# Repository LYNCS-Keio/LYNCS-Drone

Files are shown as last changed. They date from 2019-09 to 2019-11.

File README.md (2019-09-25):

# LYNCS-Drone

## Todo
- [ ] ESP32とRaspberry Pi 3間でUARTを使えるようにする
- [x] ESP32でSPI(ESP32がmaster)を使えるようにする
- [ ] MPU9255から姿勢を取得する
- [x] DPS310から温度・気圧を取得する
- [x] DPS310から高度を取得する
- [ ] ESCを使えるようにする
- [ ] 制御する

# Appearance
## 基板完成予想図
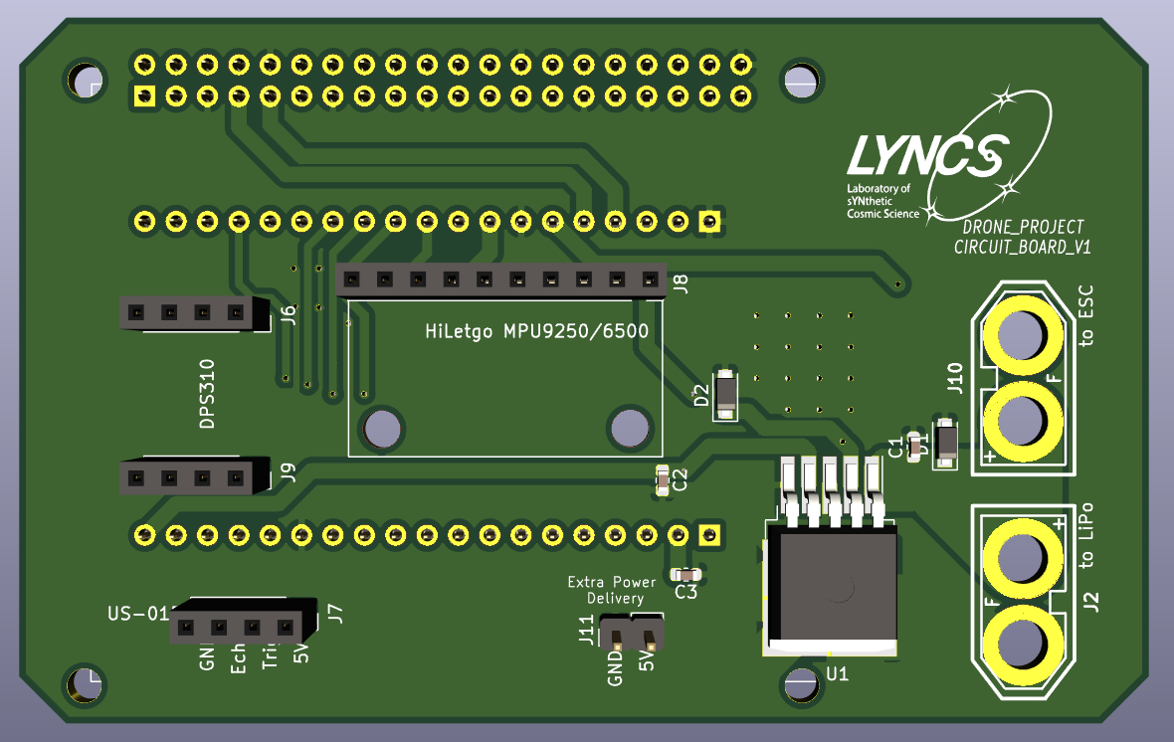
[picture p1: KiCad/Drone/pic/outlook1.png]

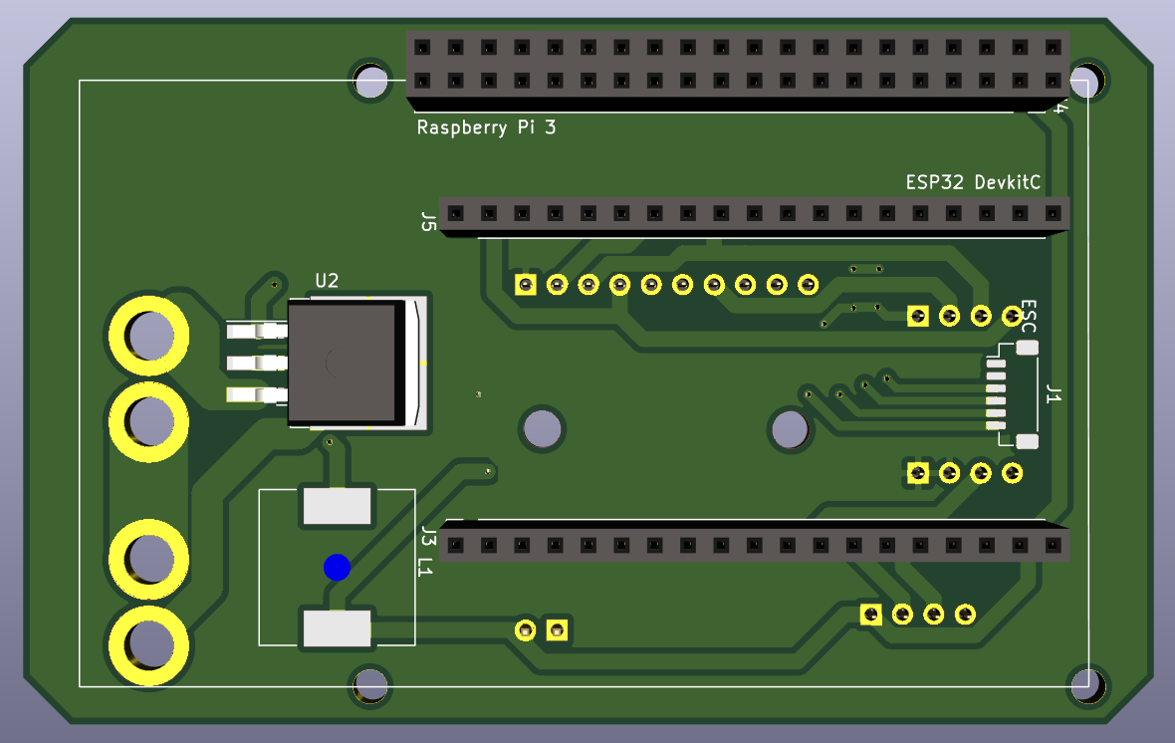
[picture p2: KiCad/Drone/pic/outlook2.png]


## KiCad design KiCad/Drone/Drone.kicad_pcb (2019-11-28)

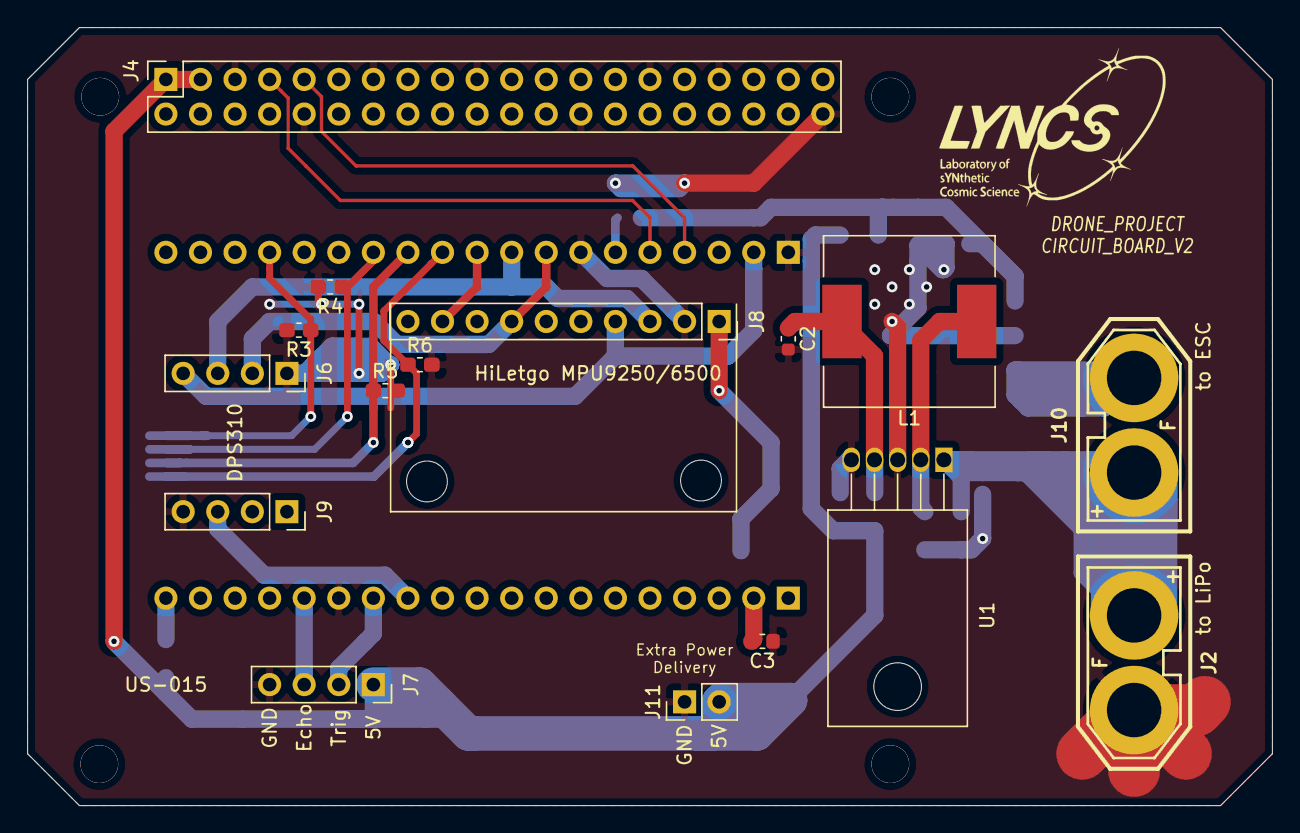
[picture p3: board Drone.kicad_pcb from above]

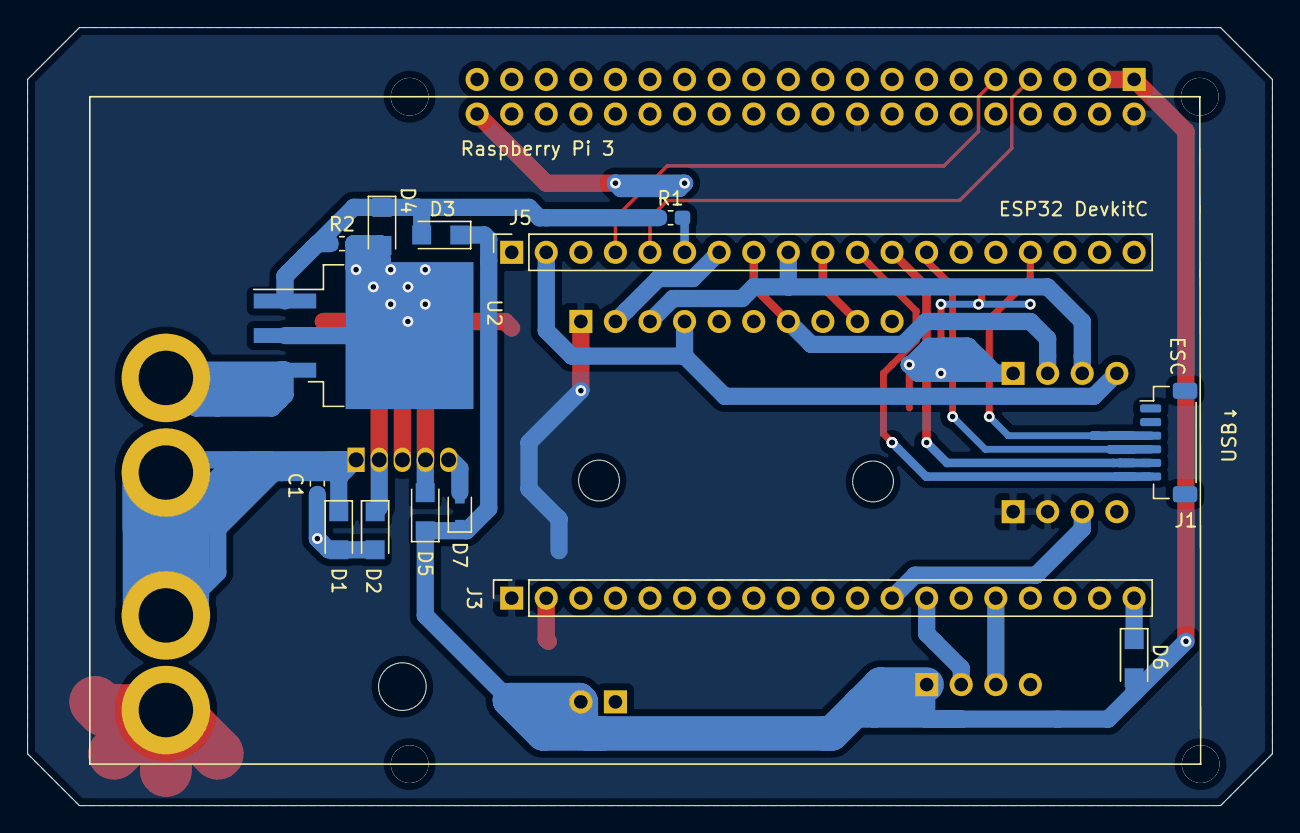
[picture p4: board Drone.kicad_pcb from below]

Board: 2 copper layers, 91.4 x 57.1 mm, 32 parts (14 on the bottom side), 24 nets.

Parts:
C1: 47u; C_0603_1608Metric
C2: 22u; C_0603_1608Metric
C3: 1u; C_0603_1608Metric
D1, D2, D3, D4, D5, D6: SS2040FL; D_SOD-123F
D7: UDZV5.1B; D_SOD-323
J1: ESC; JST_SH_BM06B-SRSS-TB_1x06-1MP_P1.00mm_Vertical
J2: BATTRY; XT-60_female
J3: ESP32_LEFT; PinSocket_1x19_P2.54mm_Vertical
J4: Raspberry Pi; PinSocket_2x20_P2.54mm_Vertical
J5: ESP32_RIGHT; PinSocket_1x19_P2.54mm_Vertical
J6: DPS310_LEFT; PinSocket_1x04_P2.54mm_Vertical
J7: US-015; PinSocket_1x04_P2.54mm_Vertical
J8: MPU9250; PinSocket_1x10_P2.54mm_Vertical
J9: DPS310_RIGHT; PinSocket_1x04_P2.54mm_Vertical
J10: to ESC Power; XT-60_female
J11: Conn_01x02_Female; PinHeader_1x02_P2.54mm_Vertical
L1: 989BS-270M; L_12x12mm_H6mm
R1: 1k; R_0603_1608Metric_Pad1.05x0.95mm_HandSolder
R2, R3, R4, R5, R6: 10k; R_0603_1608Metric_Pad1.05x0.95mm_HandSolder
U1: LM2596T-5; TO-220-5_Horizontal_TabDown
U2: SKI03021; TO-263-3_TabPin4
screw: MountingHole_3mm
screw#2: MountingHole_3mm

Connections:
3V3: J3.1, J4.2, J4.18, J8.1, J9.1, J9.2
5V: D3.1, D5.1, D6.2, D7.1, J4.1, J4.3, J7.1, J11.2
ADO: J5.8, J6.2, J8.7
BAT: C1.1, D1.1, J2.2, J10.2, U1.1
CSBN: J3.12, J9.3
EN: C3.2, J3.2
ESC_GND: J10.1, U2.3
Echo: J3.15, J7.3
GND: C1.2, C2.2, C3.1, D1.2, D2.2, D4.2, D7.2, J2.1, J3.14, J4.5, J4.10, J4.13, J4.19, J4.26, J4.29, J4.33, J4.40, J5.1, J5.7, J6.1, J7.4, J8.2, J9.4, J11.1, R2.2, R3.2, R4.2, R5.2, R6.2, U1.3, U1.5, U2.2, U2.4
GPIO4: J1.4, J5.13, R4.1
GPIO5: J5.10, J8.9
GPIO12: J3.13, J7.2
GPIO15: J1.3, J5.16, R3.1
GPIO16: J1.5, J5.12, R5.1
GPIO17: J1.6, J5.11, R6.1
GPIO18: J5.9, J6.3, J8.3
GPIO21: J5.6, R1.2
GPIO23: J5.2, J6.4, J8.4
unnamed: C2.1, D5.2, L1.2, U1.4
unnamed: D2.1, L1.1, U1.2
unnamed: D3.2, D4.1, R1.1, R2.1, U2.1
unnamed: D6.1, J3.19
PI_UART_RX: J4.9, J5.4
PI_UART_TX: J4.7, J5.5

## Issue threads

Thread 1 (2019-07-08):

BananaPiでpipenvをインストールできない

naoki-cpp, 2019-07-08:
https://qiita.com/agajo/items/73d6f14855da703972e0
で解決した。
~/.pip/pip.confに
```
[global]
trusted-host = pypi.python.org
               pypi.org
               files.pythonhosted.org
```
を書く

naoki-cpp, 2019-07-18:
無理だったのでこうした。
```
sudo python -m pip install pipenv --trusted-host=pypi.python.org --trusted-host=pypi.org --trusted-host=files.pythonhosted.org
```
でpipenvをインストールして、
https://tekunabe.hatenablog.jp/entry/2018/12/28/pyenv_pipenv に従ってpyenvをインストールした。
```
pipenv --python 3.7
```
などとすればpipenvはpyenvを用いて所望のバージョンをインストールしてくれる。

naoki-cpp, 2019-07-18:
参考
https://laboradian.com/cannot-import-name-main-when-upgrading-pip/
http://icchy.hatenablog.jp/entry/2018/04/17/064443
パッケージはpipenvでokかな

Closed 2019-07-18.

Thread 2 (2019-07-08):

BananaPiとsshする

naoki-cpp, 2019-07-08:
https://dev.banana-pi.org.cn/Image/BPI-M2Z/Raspbian/
から最新版のイメージをダウンロードし, SDカードに焼いたらBPI-BOOTにsshという名前のファイルを作る. /etc/wpa_supplicant/wpa_supplicant.confにwifiの設定を書いたら
```bash
ssh pi@bpi-iot-ros-ai.local
```
でsshできる

Closed 2019-07-08.

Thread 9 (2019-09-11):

pin_list

naoki-cpp, 2019-09-11:
ピンのリスト
- ESP32 to MPU9250
SPI:VSPI
```
ESP32
MOSI:GPIO19
MISO:GPIO18
CLK:GPIO21
SS:GPIO5
```
```
MPU9250
MOSI:SDA
MISO:ADO
CLK:SCL
SS:NCS
```
- DPS310
SPI:VSPI
```
ESP32
MOSI:GPIO19
MISO:GPIO18
CLK:GPIO21
SS:GPIO13
```
```
DPS310
MOSI:SDI
MISO:SDO
CLK:SCK
SS:CSBN
```
- US-015
```
ESP to US-015
GPIO14 - Trig
GPIO12 - Echo
```
- ESC
```
PWM1:GPIO15
PWM2:GPIO4
PWM3GPIO16
PWM4:GPIO17
```
- UART:Raspberry Pi -- ESP32
```
ESP32
TX:GPIO1
RX:GPIO3
```
```
Raspberry Pi 3
TX:GPIO14
RX:GPIO15
```

naoki-cpp, 2019-09-16:
変更
```
DPS310
MISO:19
MOSI:23
CLK:18
CS:14
```

```
MPU9250
MISO:19
MOSI:23
CLK:18
CS:5
```
```
GPIO12 - Trig
GPIO13 - Echo
```

naoki-cpp, 2019-09-19:
変更
- UART:Raspberry Pi -- ESP32
```
Raspberry Pi 3
TX:GPIO8
RX:GPIO10
```

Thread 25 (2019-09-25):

privateなどこからも参照されていない変数を削除できない

naoki-cpp, 2019-09-25:
以下の変数をコメントアウトしたり削除したりするとm_opModeがIDLEではなくなって温度や気圧を測定できなくなります。
https://github.com/LYNCS-Keio/LYNCS-Drone/blob/56b1df6193942ed0354b5db4436d97d829575eb2/ESP32/lib/DPSdriver/include/DPS.hpp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

Closed 2019-09-25.

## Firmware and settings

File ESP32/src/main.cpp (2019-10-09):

/**
 * @file main.cpp
 * Main function.
 */
// =========================================================================
// This code is placed under the MIT License
// Copyright 2019 Laboratory of sYNsetic Cosmic Science. All rights reserved.
// For the license information refer to LICENSE file in root directory.
// =========================================================================

#include <cstdio>
#include <vector>
#include "SPIbus.hpp"
#include "DPS.hpp"
#include "DPS310.hpp"
#include "MPU9255.hpp"
#include "ESCdriver.hpp"

#include "freertos/FreeRTOS.h"
#include "freertos/task.h"
#include "esp_log.h"
#include "esp_err.h"

#define DPS_SPI_CLOCK   10000000    // 10 MHz
#define DPS_SPI_MODE    3

#define DPS_MISO_PIN    19
#define DPS_MOSI_PIN    23
#define DPS_SCLK_PIN    18
#define DPS_CS_PIN      14

#define MPU_SPI_CLOCK   100000     // 100 kHz
#define MPU_SPI_MODE    3

#define MPU_MISO_PIN    19
#define MPU_MOSI_PIN    23
#define MPU_SCLK_PIN    18
#define MPU_CS_PIN      5


#define PWM_1 15
#define PWM_2 4
#define PWM_3 16
#define PWM_4 17

extern "C" void app_main()
{
    SPI_t &mySPI = hspi;  // vspi and hspi are the default objects

    spi_bus_config_t config;
    config.mosi_io_num = DPS_MOSI_PIN;
    config.miso_io_num = DPS_MISO_PIN;
    config.sclk_io_num = DPS_SCLK_PIN;
    config.quadwp_io_num = -1; // -1 not used
    config.quadhd_io_num = -1; // -1 not used
    config.max_transfer_sz = 4094;
    config.flags = 0;
    config.intr_flags = 0;
    spi_bus_initialize(HSPI_HOST, &config, 0); // 0 DMA not used
    
    dps310::DPS310 myDPS(&mySPI);
    myDPS.dev_init(DPS_SPI_MODE,DPS_SPI_CLOCK,DPS_CS_PIN);
    mpu9255::MPU9255 myMPU(&mySPI);
    myMPU.dev_init(MPU_SPI_MODE,MPU_SPI_CLOCK, MPU_CS_PIN);

    myDPS.setTmpOversamplingRate(1);
    myDPS.setPrsOversamplingRate(1);

    dps::dps_err_t ret = myDPS.initiarize();
    printf("ret=%d\n",ret);
    if (ret != dps::DPS__SUCCEEDED)
    {
        return;
    }
    
    std::vector<int> pins{PWM_1, PWM_2, PWM_3, PWM_4};

    mcpwm_config_t conf;
    conf.frequency = 50;
    conf.cmpr_a = 0;
    conf.cmpr_b = 0;
    conf.duty_mode = MCPWM_DUTY_MODE_0;
    conf.counter_mode = MCPWM_UP_COUNTER;
    
    esc::ESCdriver myESC;
    myESC.initialize(pins, conf);

    myMPU.initialize();

    vTaskDelay(1000 / portTICK_PERIOD_MS);
    while (1)
    {
        float H;
        dps::dps_err_t ret;
        ret = myDPS.measureHeightOnce(H, 1);
        printf("H= %f meter ret = %d\n",H, ret);
        float Gyro[3];
        myMPU.measureGyro(Gyro);
        printf("Gyro_x=%f\n",Gyro[0]);
        printf("Gyro_y=%f\n",Gyro[1]);
        printf("Gyro_z=%f\n",Gyro[2]);

        float Accel[3];
        myMPU.measureAccel(Accel);
        printf("Accel_x=%f\n",Accel[0]);
        printf("Accel_y=%f\n",Accel[1]);
        printf("Accel_z=%f\n",Accel[2]);
        vTaskDelay(100
         / portTICK_PERIOD_MS);
    }
}

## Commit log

2019-07-22 Platform IO (#4)
    * platform ioを用いたCI開発環境
    * .travis.ymlはrootになければならない
2019-07-23 libraryの削除
2019-07-23 I2C libs (#5)
    * Initial commit, beta state
    * Reestrutured directory and added example/test
    * adjusted log level to verbose to debug lib
    * redone directory structure
    * Created menu options for I2Cbus in menuconfig
    * add initial readme.md
    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
2019-07-24 [ADD]PID lib (#7)
    * PID制御クラスの追加
    * 積分してなかった
2019-08-07 dps310のlib（温度検出まで）
2019-09-13 SPIでMPU9250のデータを取る,SPIbusはまだ使っていません
2019-09-16 [MOD]CS_PINの変更
2019-09-16 [MOD]CS_PINの変更（回路の変更を含む）
    [Drone.kicad_pcb, Drone.sch]
2019-09-16 [DEL]deleted the function temperature
2019-09-16 [FIX]設定と書き込み関数の修正
2019-09-17 [MOD]測定間隔の単位の修正
2019-09-17 [MOD]補正値が間違っていた
2019-09-17 [MOD]高度の計算式の修正
2019-09-17 [MOD]改行の修正
2019-09-17 [MOD]initializeの修正
2019-09-17 [FIX]flushFIFO ここがすべての元凶である！！！！！！！！！スペルはちゃんと確認しようね
2019-09-17 [MOD]仮想関数の明示
2019-09-17 [MOD]m_initFailは正常初期化時に0になる
2019-09-17 [FIX?]よくわからんけど動く(?)プログラムです なんだこれ(print入れたりdelay追加すると死ぬ)
2019-09-17 [DEL]measureHeightOnceの廃止
2019-09-17 [FIX?]よくわからんけど動く(?)プログラムです なんだこれ(print入れたりdelay追加すると死ぬ)
    SPIの通信周りは自分で作らない方が良いのか…？
2019-09-18 [FIX]configの書き込み順を変えて少し安定した気がする レジスタに正しい値が書き込まれるようになった
2019-09-18 [FIX]spiWriteの中にdelayを置くと書き込みに失敗しなくなった 一方で電源を一回落とさないで連続で書き込むと読み取りに失敗してしまう
2019-09-19 [MOD]外部5V電源とマイナーな変更
    [Drone.kicad_pcb, Drone.sch]
2019-09-19 [MOD]minor change (#15)
    [Drone.kicad_pcb, Drone.sch]
2019-09-19 [MOD]esp_err_tの削除 (#17)
    * [ADD]LICENCE
    * [DEL]deleted calc_height_sub
    * [ADD]DPS__FAIL_COMMUNICATION
    * [MOD]定数の移動
    * [MOD]DPS310__BUSYTIME_FAILSAFE
    * [MOD]esp_err_tを使わないようにした
2019-09-19 [MOD]シルクスクリーンのマイナーな変更 (#16)
    * [MOD]minor change
    * [MOD]minor change
    * [MOD]UARTピンの変更
    [Drone.kicad_pcb, Drone.sch]
2019-09-19 [ADD]US015とMPUDriver
2019-09-19 [FIX]ArduinoIDE用プログラム
    回路確認用に作りました
2019-09-20 [MOD]:recycle:回路の変更 (#21)
    * [MOD]:bug:MOSFET周りの修正
    * :recycle:銅線を太くしたり
    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
    [Drone.kicad_pcb, Drone.sch]
2019-09-21 :recycle:cleaned DPSdriver (#22)
    * :pencil2: wrote some discriptions
    * :recycle:#defineをconstexprに変えた
    * :recycle:deleted unused #include
    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
2019-09-25 :bug:回路の変更 (#23)
    * :bug:ESCの位置と回路の変更
    * :recycle:微調整
    * :recycle:ESCの位置を変更
    [Drone.kicad_pcb]
2019-09-25 :recycle:regular updates (#26)
    * :shower:不要なローカル変数の削除
    * :recycle:renamed DPS__FAIL_TOO_BUSY
    * :bug:standbyを追加
    * :shower:deleted unnecessary return
    * :shower:fixes #25
2019-09-27 :recycle:refactor DPSdriver (#27)
    * :shower:removed unused argument
    * :recycle:2回以上のdev_initに対応
    * :recycle:renamed some variables
2019-09-27 :fire:Daily Update DPSdriver (#28)
    * :fire:dps_init
    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
2019-09-27 :recycle:コンストラクタの引数を変えた
2019-09-27 :construction:後処理の追加
2019-09-27 :construction:m_dev_init_を追加して2回以上のdev_initに対応した
2019-09-27 :construction:MPUのSPI設定の追加
2019-10-02 :construction:Who Am Iの取得に成功
2019-10-02 mcpwm使うとうまく行った (#13)
    * mcpwm使うとうまく行った
    * remove unnecessary comment
    * :pencil2:fixed typo
    * :construction:namespace esc
    * move roopcounter into static valuable
    [main.cpp]
2019-10-02 :construction:initializeは間違ったデバイスを検知する
2019-10-05 :fire:DPS310のソケットの位置を修正
    [Drone.kicad_pcb]
2019-10-05 :construction:setGyroFullScaleSelectを公開
2019-10-06 :pencil2:シルクの位置を調整
    [Drone.kicad_pcb]
2019-10-06 :fire:テスト用ファイルの削除
2019-11-01 :bug:raspberry pi の配置の修正など
    [Drone.kicad_pcb, Drone.sch]
2019-11-08 :+1:update schematic
    [Drone.kicad_pcb]
2019-11-16 :+1:mosfetの保護
    [Drone.sch]
